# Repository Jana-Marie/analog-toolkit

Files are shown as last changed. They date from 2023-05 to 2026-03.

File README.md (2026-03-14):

# permanently moved to [codeberg/analog-toolkit](https://codeberg.org/analog-toolkit)

# analog-toolkit
A small and simple STM32G431 based dev board, doubling as a simple analog-to-USB acquisition tool.

Next to 6 single ended or 2 differential ADC inputs, there are 3 PGA connected ADC channels, 3 general purpose IO, 2 DAC outputs, 2 Timer outputs, and several protocols such as UART, I2C, USB FS and USB-PD. All ADCs have a standard input resolution of 12 bits, with hardware oversampling up to 16 bits, the DAC has 12 bits resolution. 
Equiped with a DFU bootloader, this board can simply be flashed from USB. All Ports are available through standard 2.54mm pinheader, a scope aligator clip can be attached to the grounding tab. A RGB led allows for direct status indication.

<table>
  <tbody>
    <tr>
      <td>
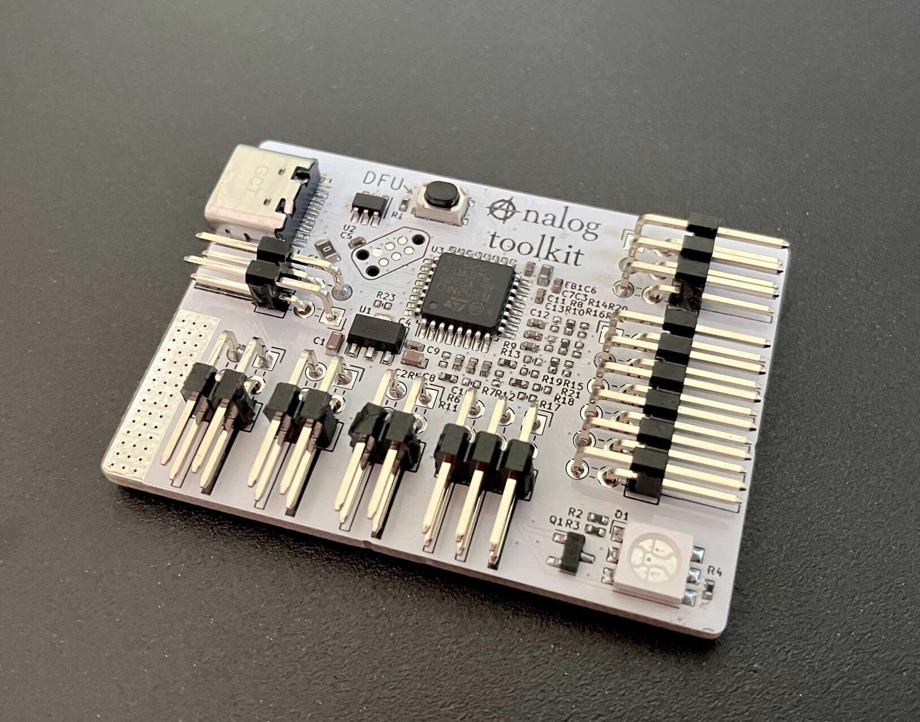
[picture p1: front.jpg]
A white pcb reading “analog toolkit”, where the a is an anarchy a. There is a MCU, USB, pin headers and a led
        
      </td>
      <td>
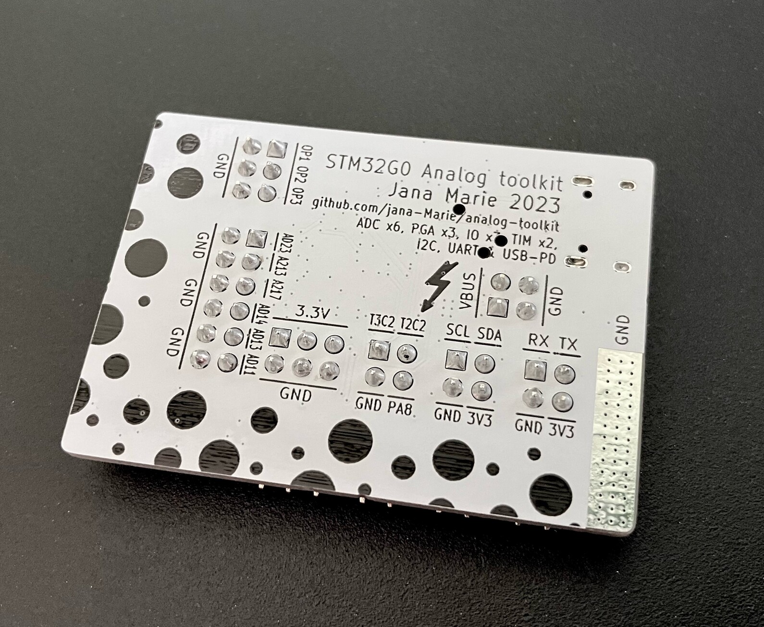
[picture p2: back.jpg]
Back side of the pcb with pin annotations, and some more informations on the hw, as well as silkscreen art
        
      </td>
    </tr>
    <tr>
      <td colspan="2">
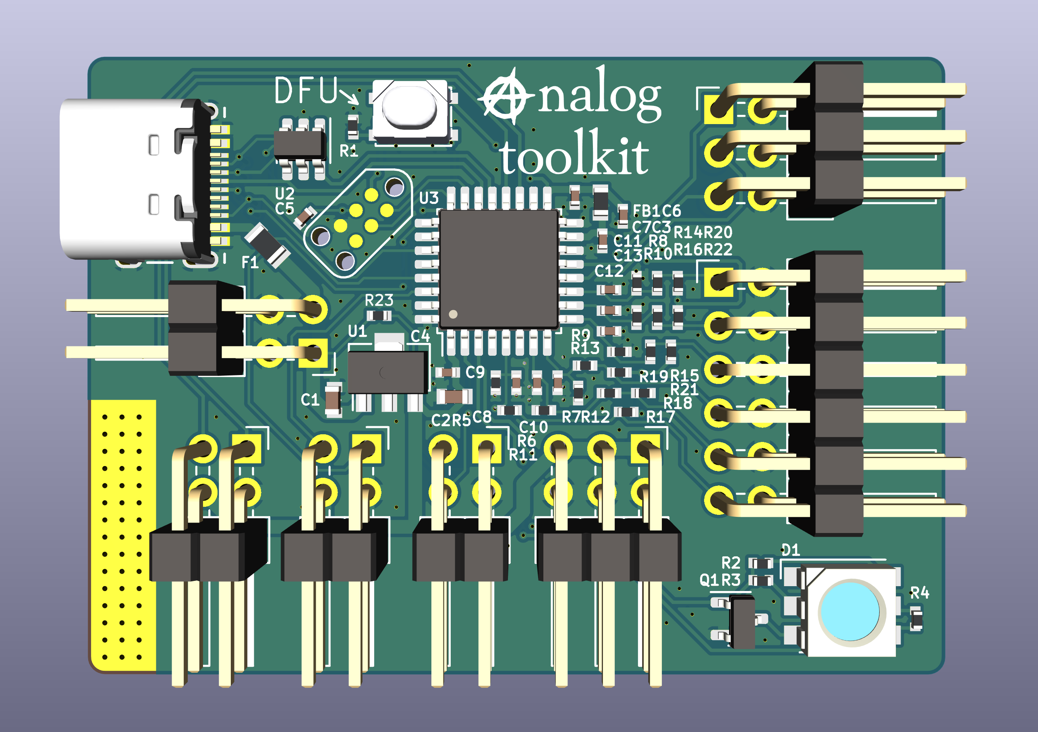
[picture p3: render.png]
render of front side of pcb
        
      </td>
    </tr>
  </tbody>
</table>

## folder structure
```
 /hardware          - PCB files
 /ADC               - ADC sampling firmware, with selectable samplerate and API
 /ADC/software      - python receiving sketch for ADC firmware
 /DAC/              - DAC firmware bit, this one doesn't do much yet
 /pd-dev/           - USB-PD Sink firmware
```

## things I want to do and explore

#### HW

 - [x] replace RGB led with two discrete LEDs
 - [x] cheaper JLC version, keep functionality
 
#### SW/FW

 - [ ] build CLI
   - [ ] build basic CLI firmware
 - [ ] improve ADC fw
   - [ ] add interactive python console (60% done)
   - [ ] PGA current and temperature sensing
   - [ ] Implement byte stuffing
 - [ ] improve DAC fw
   - [ ] make sample rate settable
   - [ ] make sample settable
 - [ ] Implement Sigrok protocol
 - [ ] Implement SCPI
 - [x] USB-PD firmware
 
## license
 
Copyright Jana Marie Hemsing 2026.

This source describes Open Hardware and is licensed under the CERN-OHL-S v2.

You may redistribute and modify this source and make products using it under the terms of the CERN-OHL-S v2 (https://ohwr.org/cern_ohl_s_v2.txt).

This source is distributed WITHOUT ANY EXPRESS OR IMPLIED WARRANTY, INCLUDING OF MERCHANTABILITY, SATISFACTORY QUALITY AND FITNESS FOR A PARTICULAR PURPOSE. Please see the CERN-OHL-S v2 for applicable conditions.

Source location: https://github.com/Jana-Marie/analog-toolkit

As per CERN-OHL-S v2 section 4, should You produce hardware based on this source, You must where practicable maintain the Source Location visible on the external case of the Gizmo or other products you make using this source.

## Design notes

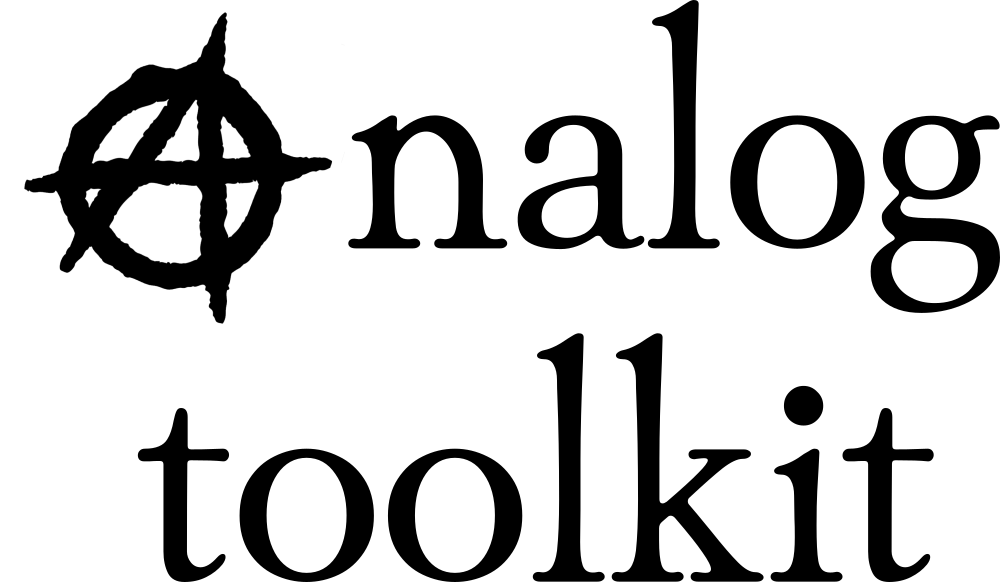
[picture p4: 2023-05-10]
g1298.png

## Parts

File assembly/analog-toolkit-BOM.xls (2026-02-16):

Id | Designator | Footprint | Quantity | Comment | JLCPCB
1 | J1 | USB-C 16Pin | 1 | USB_C | C165948
2 | R4,R2,R3,R1 | R_0402 | 4 | 5k1 | C25905
3 | J2 | PinHeader_2x02_P2.54mm_Horizontal | 1 | IO | C5383087
4 | Q1 | SOT-23 | 1 | AO3400A | C20917
6 | J3 | PinHeader_2x02_P2.54mm_Horizontal | 1 | UART | C5383087
7 | J8 | PinHeader_2x06_P2.54mm_Horizontal | 1 | ADC | C5383091
8 | J6 | PinHeader_2x03_P2.54mm_Horizontal | 1 | 3.3V | C5383088
9 | J4 | PinHeader_2x02_P2.54mm_Horizontal | 1 | I2C | C5383087
10 | C7,C6,C5,C3,C4 | C_0402 | 5 | 100n | C1525
11 | R14,R12,R16,R11,R13,R15 | R_0402 | 6 | 0 | C17168
12 | C12,C11,C8,C9,C10,C13 | C_0402 | 6 | 10n | C15195
13 | U1 | SOT-89-3 | 1 | AP2204R-3.3 | C156303
14 | U2 | SOT-23-6 | 1 | otter_USBLC6-4 | C111212
16 | D1 | LED_RGB_5050-6 | 1 | LED_RGB | C440457
17 | U3 | LQFP-32_7x7mm_P0.8mm | 1 | STM32G431KBT6 | C529357
18 | J5 | PinHeader_2x02_P2.54mm_Horizontal | 1 | VBUS | C5383087
19 | F1 | R_0805 | 1 | 500mA | C17477
20 | FB1 | R_0603 | 1 | FERRET | C1002
21 | C2,C1 | C_0603 | 2 | 4u7 | C19666
22 | SW1 | SW_SPST_PTS810 | 1 | DFU | C115360
23 | J7 | PinHeader_2x03_P2.54mm_Horizontal | 1 | OPAMP | C5383088

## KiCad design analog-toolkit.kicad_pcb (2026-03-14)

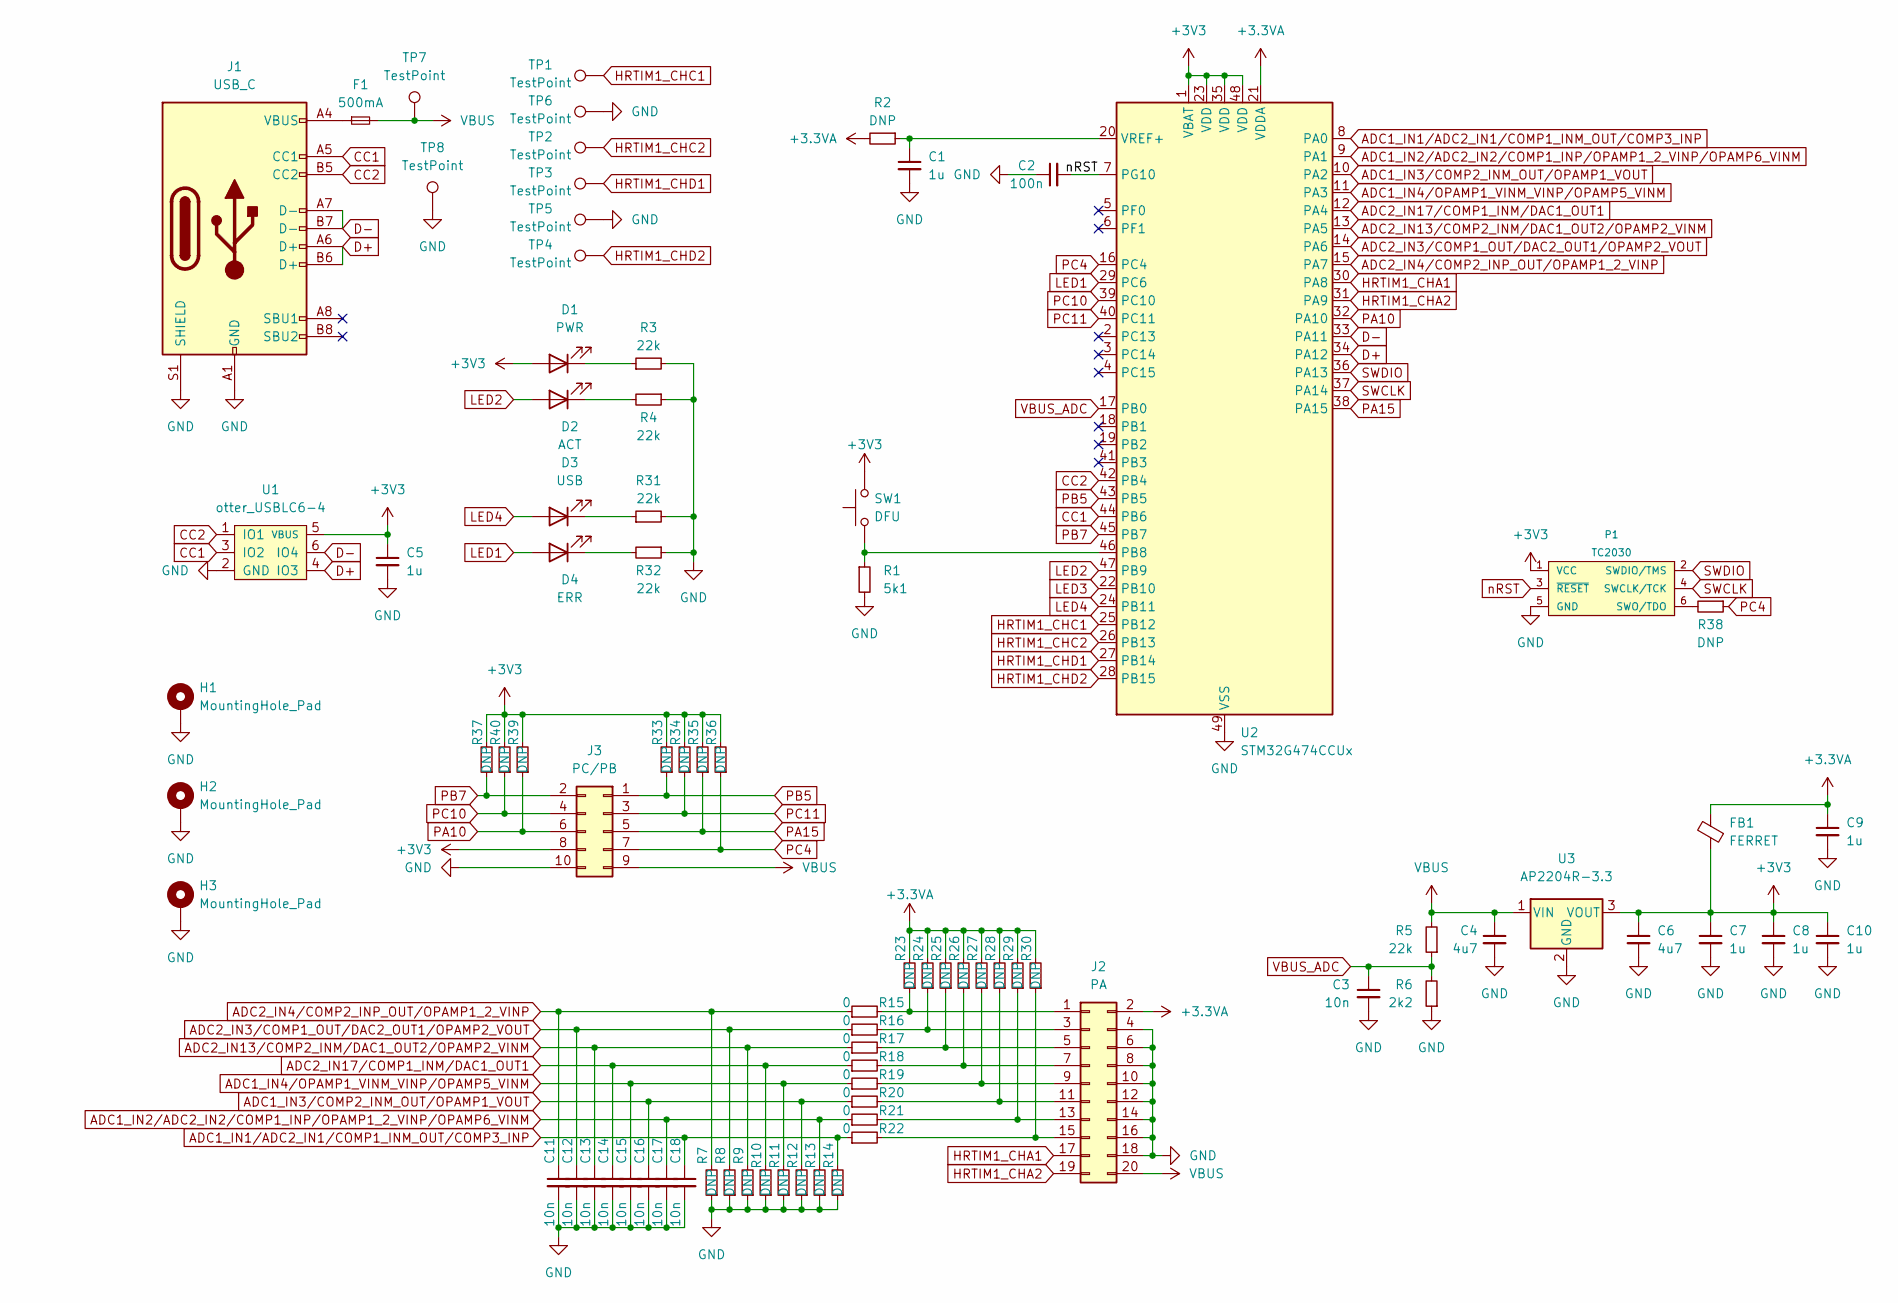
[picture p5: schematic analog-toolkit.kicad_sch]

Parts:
C1, C5, C7, C8, C9, C10: 1u; C_0402; lcsc C52923
C2: 100n; C_0402
C3, C11, C12, C13, C14, C15, C16, C17, C18: 10n; C_0402; lcsc C15195
C4, C6: 4u7; C_0805; lcsc C1779
D1: PWR; LED_0805_2012Metric
D2: ACT; LED_0805_2012Metric
D3: USB; LED_0805_2012Metric
D4: ERR; LED_0805_2012Metric
F1: 500mA; R_0805
FB1: FERRET; R_0603; lcsc C1002
H1, H2, H3: MountingHole_Pad; MountingHole_2.2mm_M2_ISO7380_Pad
J1: USB_C; USB-C 16Pin
J2: PA; IDC-Header_2x10_P2.54mm_Horizontal
J3: PC/PB; IDC-Header_2x05_P2.54mm_Horizontal
P1: TC2030
R1: 5k1; R_0402
R2, R7, R8, R9, R10, R11, R12, R13, R14, R23, R24, R25, R26, R27, R28, R29, R30, R33, R34, R35, R36, R37, R38, R39, R40: DNP; R_0402
R3, R4, R31, R32: 22k; R_0402
R5: 22k; R_0402; lcsc C25768
R6: 2k2; R_0402; lcsc C25890
R15, R16, R17, R18, R19, R20, R21, R22: 0; R_0402; lcsc C17168
SW1: DFU; SW_SPST_PTS810
TP1, TP2, TP3, TP4, TP5, TP6, TP7, TP8: TestPoint; TestPoint_Pad_1.0x1.0mm
U1: otter_USBLC6-4; SOT-23-6
U2: STM32G474CCUx; QFN-48-1EP_7x7mm_P0.5mm_EP5.6x5.6mm
U3: AP2204R-3.3; SOT-89-3

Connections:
+3.3VA: C9.1, FB1.2, J2.2, R2.2, R23.2, R24.2, R25.2, R26.2, R27.2, R28.2, R29.2, R30.2, U2.21 (VDDA)
+3V3: C5.1, C6.1, C7.1, C8.1, C10.1, D1.2 (A), FB1.1, J3.8, P1.1 (VCC), R33.2, R34.2, R35.2, R36.2, R37.2, R39.2, R40.2, SW1.2, U1.5 (VBUS), U2.1 (VBAT), U2.23 (VDD), U2.35 (VDD), U2.48 (VDD), U3.3 (VOUT)
ADC1_IN1/ADC2_IN1/COMP1_INM_OUT/COMP3_INP: C18.1, R14.2, R22.1, U2.8 (PA0)
ADC1_IN2/ADC2_IN2/COMP1_INP/OPAMP1_2_VINP/OPAMP6_VINM: C17.1, R13.2, R21.1, U2.9 (PA1)
ADC1_IN3/COMP2_INM_OUT/OPAMP1_VOUT: C16.1, R12.2, R20.1, U2.10 (PA2)
ADC1_IN4/OPAMP1_VINM_VINP/OPAMP5_VINM: C15.1, R11.2, R19.1, U2.11 (PA3)
ADC2_IN3/COMP1_OUT/DAC2_OUT1/OPAMP2_VOUT: C12.1, R8.2, R16.1, U2.14 (PA6)
ADC2_IN4/COMP2_INP_OUT/OPAMP1_2_VINP: C11.1, R7.2, R15.1, U2.15 (PA7)
ADC2_IN13/COMP2_INM/DAC1_OUT2/OPAMP2_VINM: C13.1, R9.2, R17.1, U2.13 (PA5)
ADC2_IN17/COMP1_INM/DAC1_OUT1: C14.1, R10.2, R18.1, U2.12 (PA4)
CC1: J1.A5 (CC1), U1.3 (IO2), U2.44 (PB6)
CC2: J1.B5 (CC2), U1.1 (IO1), U2.42 (PB4)
D+: J1.A6 (D+), J1.B6 (D+), U1.4 (IO3), U2.34 (PA12)
D-: J1.A7 (D-), J1.B7 (D-), U1.6 (IO4), U2.33 (PA11)
GND: C1.2, C2.1, C3.2, C4.2, C5.2, C6.2, C7.2, C8.2, C9.2, C10.2, C11.2, C12.2, C13.2, C14.2, C15.2, C16.2, C17.2, C18.2, H1.1, H2.1, H3.1, J1.A1 (GND), J1.A12 (GND), J1.B1 (GND), J1.B12 (GND), J1.S1 (SHIELD), J2.4, J2.6, J2.8, J2.10, J2.12, J2.14, J2.16, J2.18, J3.10, P1.5 (GND), R1.2, R3.2, R4.1, R6.1, R7.1, R8.1, R9.1, R10.1, R11.1, R12.1, R13.1, R14.1, R31.2, R32.1, TP5.1, TP6.1, TP8.1, U1.2 (GND), U2.49 (VSS), U3.2 (GND)
HRTIM1_CHA1: J2.17, U2.30 (PA8)
HRTIM1_CHA2: J2.19, U2.31 (PA9)
HRTIM1_CHC1: TP1.1, U2.25 (PB12)
HRTIM1_CHC2: TP2.1, U2.26 (PB13)
HRTIM1_CHD1: TP3.1, U2.27 (PB14)
HRTIM1_CHD2: TP4.1, U2.28 (PB15)
LED1: D4.2 (A), U2.29 (PC6)
LED2: D2.2 (A), U2.47 (PB9)
LED3: U2.22 (PB10)
LED4: D3.2 (A), U2.24 (PB11)
unnamed: D1.1 (K), R3.1
unnamed: D2.1 (K), R4.2
unnamed: D3.1 (K), R31.1
unnamed: D4.1 (K), R32.2
unnamed: F1.1, J1.A4 (VBUS), J1.A9 (VBUS), J1.B4 (VBUS), J1.B9 (VBUS)
unnamed: J2.1, R15.2, R23.1
unnamed: J2.3, R16.2, R24.1
unnamed: J2.5, R17.2, R25.1
unnamed: J2.7, R18.2, R26.1
unnamed: J2.9, R19.2, R27.1
unnamed: J2.11, R20.2, R28.1
unnamed: J2.13, R21.2, R29.1
unnamed: J2.15, R22.2, R30.1
unnamed: P1.6 (SWO/TDO), R38.2
unnamed: R1.1, SW1.1, U2.46 (PB8)
unnamed: C1.1, R2.1, U2.20 (VREF+)
PA10: J3.6, R39.1, U2.32 (PA10)
PA15: J3.5, R35.1, U2.38 (PA15)
PB5: J3.1, R33.1, U2.43 (PB5)
PB7: J3.2, R37.1, U2.45 (PB7)
PC4: J3.7, R36.1, R38.1, U2.16 (PC4)
PC10: J3.4, R40.1, U2.39 (PC10)
PC11: J3.3, R34.1, U2.40 (PC11)
SWCLK: P1.4 (SWCLK/TCK), U2.37 (PA14)
SWDIO: P1.2 (SWDIO/TMS), U2.36 (PA13)
VBUS: C4.1, F1.2, J2.20, J3.9, R5.2, TP7.1, U3.1 (VIN)
VBUS_ADC: C3.1, R5.1, R6.2, U2.17 (PB0)
nRST: C2.2, P1.3 (~RESET), U2.7 (PG10)

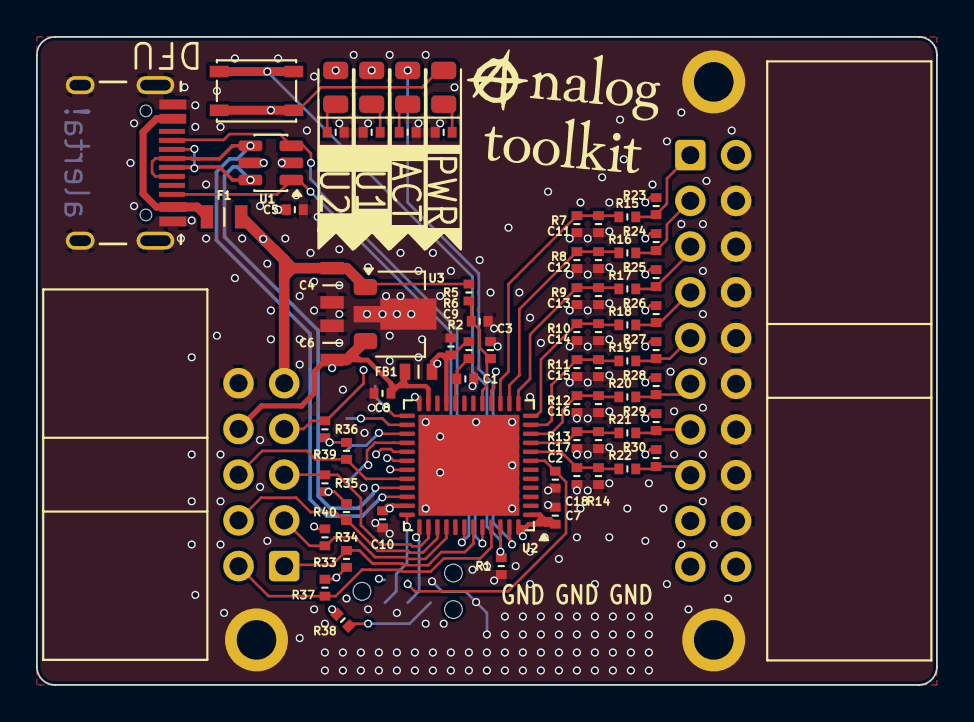
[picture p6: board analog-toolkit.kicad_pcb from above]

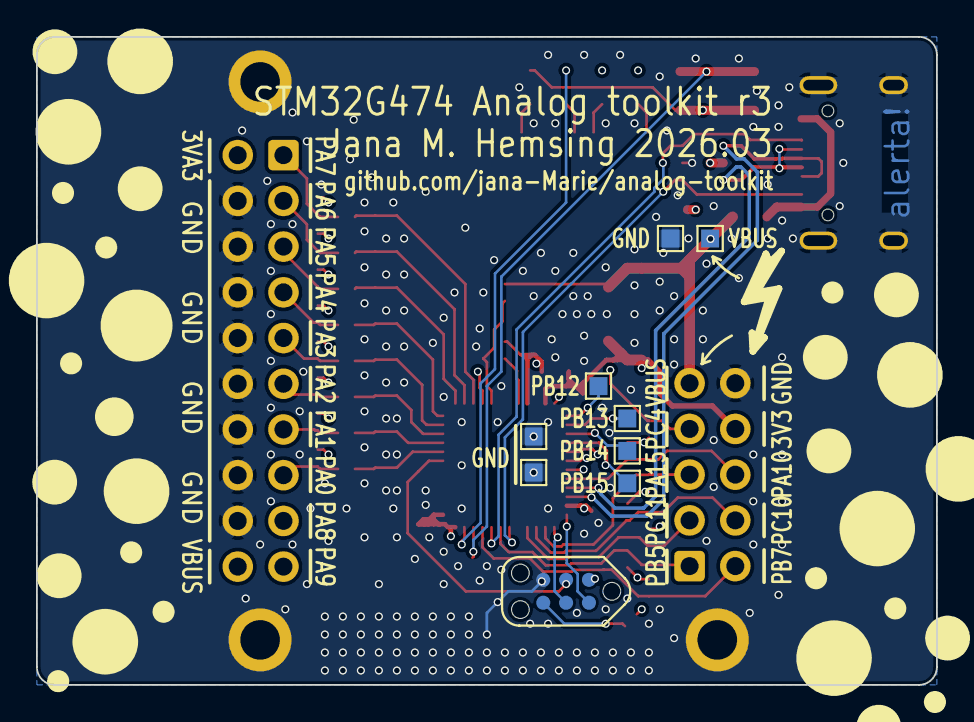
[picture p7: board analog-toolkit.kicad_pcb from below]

Board: 4 copper layers, 50.0 x 36.0 mm, 83 parts (9 on the bottom side), 52 nets.

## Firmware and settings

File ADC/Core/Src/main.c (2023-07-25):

#include "main.h"
#include "usbpd.h"
#include "usb_device.h"
#include "usbd_cdc_if.h"
//#include <math.h>

#define CLAMP(x, low, high) (((x) > (high)) ? (high) : (((x) < (low)) ? (low) : (x)))
#define ABS(x) ((x) < 0 ? -(x) : (x))

ADC_HandleTypeDef hadc1;
ADC_HandleTypeDef hadc2;
DMA_HandleTypeDef hdma_adc1;
DMA_HandleTypeDef hdma_adc2;

CORDIC_HandleTypeDef hcordic;

FMAC_HandleTypeDef hfmac;

I2C_HandleTypeDef hi2c1;

OPAMP_HandleTypeDef hopamp1;
OPAMP_HandleTypeDef hopamp2;
OPAMP_HandleTypeDef hopamp3;

RNG_HandleTypeDef hrng;

TIM_HandleTypeDef htim2;
TIM_HandleTypeDef htim3;
TIM_HandleTypeDef htim4;
TIM_HandleTypeDef htim6;
TIM_HandleTypeDef htim8;

UART_HandleTypeDef huart1;

enum led_states {LED_OFF = 0, LED_READY, LED_RUNNING, LED_DONE, LED_ERROR};
enum fsm_states {IDLE = 0, INIT, RUNNING, DONE, ERR};

// FLAGS
uint8_t evaluate_FSM = 0;

struct fsm_t {
  uint8_t led; // led mode
  uint8_t mode; // FSM mode
} fsm;

uint16_t adc[9]; // ADC buf

struct settings_t {
  uint32_t samplingFreq; // sampling frequency
  uint16_t psc; // sampling frequency
  uint16_t arr; // sampling frequency
  uint16_t OverSampling; // oversampling ration; 0, x2, x4, x8, x16
  uint16_t PGAgain[3]; // PGA gain
  uint8_t configChanged; // flag for config has changed 2^0 frequency has changed; 2^1 psc, arr has changed; 2^2 PGA has changed
  uint8_t telegramSize;
} settings;

uint8_t usbDataReady; // flag for data ready
uint16_t usbDataLength; // length of USB data
uint8_t usbBuf[32]; // data buffer

uint8_t adcDMAready = 0;
struct telegram_t {
  uint16_t data[257][9];
  uint16_t idx; // current index
  uint16_t lastidx; // last index
  uint16_t sendcnt; // send counter
} t;

struct usb_t {
  uint8_t state; // state to determine wether the USB send flag should be set
  uint8_t send; // flag for USB send
  uint8_t res; // usb send result flag
} usb;

void SystemClock_Config(void);
static void MX_GPIO_Init(void);
static void MX_DMA_Init(void);
static void MX_UCPD1_Init(void);
static void MX_ADC1_Init(void);
static void MX_ADC2_Init(void);
static void MX_OPAMP1_Init(void);
static void MX_OPAMP2_Init(void);
static void MX_OPAMP3_Init(void);
static void MX_I2C1_Init(void);
static void MX_USART1_UART_Init(void);
static void MX_CORDIC_Init(void);
static void MX_FMAC_Init(void);
static void MX_RNG_Init(void);
static void MX_TIM2_Init(void);
static void MX_TIM3_Init(void);
static void MX_TIM4_Init(void);
static void MX_TIM8_Init(void);
static void MX_TIM6_Init(void);
void led_task(void);
void get_timer_value(struct settings_t *set);
void settings_task(struct settings_t *set);
void adc_task(void);
void fsm_task(void);
void send_usb(uint8_t len);
void usb_parser(void);

int main(void)
{
  HAL_Init();
  SystemClock_Config();
  MX_GPIO_Init();
  MX_DMA_Init();
  MX_UCPD1_Init();
  MX_USB_Device_Init();
  MX_ADC1_Init();
  MX_ADC2_Init();
  MX_OPAMP1_Init();
  MX_OPAMP2_Init();
  MX_OPAMP3_Init();
  MX_I2C1_Init();
  MX_USART1_UART_Init();
  MX_CORDIC_Init();
  MX_FMAC_Init();
  MX_RNG_Init();
  MX_TIM2_Init();
  MX_TIM3_Init();
  MX_TIM4_Init();
  MX_TIM8_Init();
  MX_TIM6_Init();

  // LED
  HAL_TIM_Base_Start_IT(&htim6);
  // ADC
  HAL_ADC_Start_DMA(&hadc1, (uint32_t *) &adc[0], 4);
  HAL_ADC_Start_DMA(&hadc2, (uint32_t *) &adc[4], 5);
  HAL_TIM_Base_Start_IT(&htim4);

  settings.samplingFreq = 100;
  settings.configChanged = 1;
  settings.telegramSize = 127;

  //MX_USBPD_Init();
  while (1)
  {
    //USBPD_DPM_Run();
    settings_task(&settings);

    //if(adc_ready) adc_task();
    if(evaluate_FSM) fsm_task();
    //if(evaluate_LED) led_task();
    if(usbDataReady) usb_parser();

  }
}

uint32_t number;
void usb_parser(){
  if(usbDataLength >= 4){
    // extract channel number, char - 48 (or ascii '0') = sent integer
    //uint8_t channel = usb_buf[3] - '0';
    number = atoi((char *)usbBuf + 3);

    if(strncmp("SPS", (char *) usbBuf, 3) == 0){
      if(number > 0 && number < 100000){
        settings.samplingFreq = number;
      }
    } else if(strncmp("SET", (char *) usbBuf, 3) == 0) {
      settings.configChanged = 1;
    }
    // else if(strncmp("RST", (char *) usb_buf, 3) == 0){
    //  t[channel].rst = 1;
    //}

    /*else if(strncmp("STR", (char *) usb_buf, 3) == 0){
      telegram[channel].usb.state = 1;
    } else if(strncmp("STP", (char *) usb_buf, 3) == 0){
      telegram[channel].usb.state = 0;
    } else if(strncmp("STP", (char *) usb_buf, 3) == 0){
      telegram[channel].usb.state = 0;
    } else if(strncmp("STP", (char *) usb_buf, 3) == 0){
      telegram[channel].usb.state = 0;
    } else if(strncmp("HST", (char *) usb_buf, 3) == 0){
      for(uint8_t i = 0; i <= HISTORY-1; i++){
        send_telegram(telegram[channel].serialNumber, &telegram[channel].hist[i]);
      }
    } else if(strncmp("TSK", (char *) usb_buf, 3) == 0){
      memcpy((void *)&t[channel], (void *)&usb_buf[4], 28);
    } else {
      CDC_Transmit_FS((uint8_t *) "Could not parse command\r\n", 25);
    }
    */
  }
  usbDataReady = 0;
}

uint8_t idx = 0;
uint16_t curridx;
void send_usb(uint8_t len){
  if(t.idx == 0){
    idx = 255;
  } else {
    idx = t.idx;
  }

  HAL_GPIO_WritePin(GPIOF, GPIO_PIN_1, 1);

  char package[len][56];
  for(uint16_t i = 0; i < len; i++){
    memset(package[i], '\0' , 56);
    curridx = (i + t.lastidx) % 256;
    sprintf(package[i], "%lu,%u,%u,%u,%u,%u,%u,%u,%u,%u\r\n", HAL_GetTick(),
                                                              t.data[curridx][0],
                                                              t.data[curridx][1],
                                                              t.data[curridx][2],
                                                              t.data[curridx][3],
                                                              t.data[curridx][4],
                                                              t.data[curridx][5],
                                                              t.data[curridx][6],
                                                              t.data[curridx][7],
                                                              t.data[curridx][8]);
  }

  usb.res = CDC_Transmit_FS((uint8_t *) package, 56*len);

  t.lastidx = idx;

  HAL_GPIO_WritePin(GPIOF, GPIO_PIN_1, 0);
}

uint8_t idxdif = 0;
void adc_task(){
  if(adcDMAready == 3){
    adcDMAready = 0;
    memcpy(&t.data[t.idx][0], &adc[0], 18);

    t.idx = (t.idx <= 255) ? (t.idx + 1) : 0;

    t.sendcnt++;

    if(t.sendcnt > settings.telegramSize){
      send_usb(t.sendcnt);
      t.sendcnt = 0;
    }
  }
}

// finite state machine
void fsm_task(){
    switch (fsm.mode){
      case IDLE:
      default:
        // Idle means:
        //   - Adapt to settings
        //   - Start on USB command

        if(0){
          fsm.mode = ERROR;
        } else if(0){
          fsm.mode = RUNNING;
        }
        break;
      case INIT:
        // ADC
        HAL_ADC_Start_DMA(&hadc1, (uint32_t *) &adc[0], 4);
        HAL_ADC_Start_DMA(&hadc2, (uint32_t *) &adc[4], 5);
        HAL_TIM_Base_Start_IT(&htim4);

        t.idx = 0;

        if(0){
          fsm.mode = ERROR;
        } else {
          fsm.mode = RUNNING;
        }
        break;
      case RUNNING:
        // Running means:
        //   - Collect ADC Samples
        //   - Send to USB
        //   - Adapt to change in settings
        
        usb.send = 1;
        

        if(0){
          fsm.mode = ERROR;
        } else if(0){
          fsm.mode = DONE;
        }
        break;
      case DONE:
        // Done means:
        //   - Finished with the task
        //   - Cleanup and return to IDLE

        if(0){
          fsm.mode = IDLE;
        }
        break;
      case ERR:
        // Error means:
        //   - Something went wrong, not sure what this means yet

        // if error reset
        if(0){
          fsm.mode = IDLE;
        }
        break;
    }
}

void led_task(){
  /*
  switch (fsm.led){
  case LED_OFF:
  default:
    HAL_GPIO_WritePin(GPIOF, GPIO_PIN_0, 0);
    HAL_GPIO_WritePin(GPIOF, GPIO_PIN_1, 0);
    break;
  case LED_READY:
    HAL_GPIO_WritePin(GPIOF, GPIO_PIN_0, 0);
    HAL_GPIO_WritePin(GPIOF, GPIO_PIN_1, 1);
    break;
  case LED_RUNNING:
    HAL_GPIO_WritePin(GPIOF, GPIO_PIN_0, 1);
    HAL_GPIO_TogglePin(GPIOF, GPIO_PIN_1);
    break;
  case LED_DONE:
    if(HAL_GPIO_ReadPin(GPIOF, GPIO_PIN_0) == HAL_GPIO_ReadPin(GPIOF, GPIO_PIN_1))HAL_GPIO_TogglePin(GPIOF, GPIO_PIN_0);
    HAL_GPIO_TogglePin(GPIOF, GPIO_PIN_0);
    HAL_GPIO_TogglePin(GPIOF, GPIO_PIN_1);
    break;
  case LED_ERROR:
    HAL_GPIO_WritePin(GPIOF, GPIO_PIN_0, 1);
    HAL_GPIO_WritePin(GPIOF, GPIO_PIN_1, 0);
    break;
  }
  */
}

// settings
void settings_task(struct settings_t *set){
  if(set->configChanged == 1){
    get_timer_value(set);
    set->configChanged &= ~(1);
  }
  if(set->configChanged == 2){
    set->configChanged &= ~(1 << 1);
    __HAL_TIM_SET_PRESCALER(&htim4, set->psc);
    TIM4->ARR = set->arr;

    settings.telegramSize = CLAMP(settings.samplingFreq / 10, 1, 196);
  }

}

uint32_t fake_power(uint32_t m, uint32_t n){
  if(n <= 0) return 0;
  uint32_t result = 10;
  for(uint8_t i = 0; i < n-1; i++){
    result *= 10;
  }
  return result;
}

// calculate timer values
void get_timer_value(struct settings_t *set){
    uint32_t num = 168000000/set->samplingFreq;
    uint8_t n = 0;
    while (num > 65534) {
      n += 1;
      num = num/10;
    };
    set->psc = fake_power(10, n);
    if(set->psc > 0) set->psc -= 1;
    set->arr = num - 1;
    set->configChanged += 2;
}

void SystemClock_Config(void)
{
  RCC_OscInitTypeDef RCC_OscInitStruct = {0};
  RCC_ClkInitTypeDef RCC_ClkInitStruct = {0};

  HAL_PWREx_ControlVoltageScaling(PWR_REGULATOR_VOLTAGE_SCALE1_BOOST);

  RCC_OscInitStruct.OscillatorType = RCC_OSCILLATORTYPE_HSI|RCC_OSCILLATORTYPE_HSI48;
  RCC_OscInitStruct.HSIState = RCC_HSI_ON;
  RCC_OscInitStruct.HSICalibrationValue = RCC_HSICALIBRATION_DEFAULT;
  RCC_OscInitStruct.HSI48State = RCC_HSI48_ON;
  RCC_OscInitStruct.PLL.PLLState = RCC_PLL_ON;
  RCC_OscInitStruct.PLL.PLLSource = RCC_PLLSOURCE_HSI;
  RCC_OscInitStruct.PLL.PLLM = RCC_PLLM_DIV1;
  RCC_OscInitStruct.PLL.PLLN = 21;
  RCC_OscInitStruct.PLL.PLLP = RCC_PLLP_DIV2;
  RCC_OscInitStruct.PLL.PLLQ = RCC_PLLQ_DIV4;
  RCC_OscInitStruct.PLL.PLLR = RCC_PLLR_DIV2;
  HAL_RCC_OscConfig(&RCC_OscInitStruct);
  
  RCC_ClkInitStruct.ClockType = RCC_CLOCKTYPE_HCLK|RCC_CLOCKTYPE_SYSCLK
                              |RCC_CLOCKTYPE_PCLK1|RCC_CLOCKTYPE_PCLK2;
  RCC_ClkInitStruct.SYSCLKSource = RCC_SYSCLKSOURCE_PLLCLK;
  RCC_ClkInitStruct.AHBCLKDivider = RCC_SYSCLK_DIV1;
  RCC_ClkInitStruct.APB1CLKDivider = RCC_HCLK_DIV1;
  RCC_ClkInitStruct.APB2CLKDivider = RCC_HCLK_DIV1;

  HAL_RCC_ClockConfig(&RCC_ClkInitStruct, FLASH_LATENCY_4);
}

static void MX_ADC1_Init(void)
{
  ADC_MultiModeTypeDef multimode = {0};
  ADC_ChannelConfTypeDef sConfig = {0};

  hadc1.Instance = ADC1;
  hadc1.Init.ClockPrescaler = ADC_CLOCK_SYNC_PCLK_DIV4;
  hadc1.Init.Resolution = ADC_RESOLUTION_12B;
  hadc1.Init.DataAlign = ADC_DATAALIGN_RIGHT;
  hadc1.Init.GainCompensation = 0;
  hadc1.Init.ScanConvMode = ADC_SCAN_ENABLE;
  hadc1.Init.EOCSelection = ADC_EOC_SEQ_CONV;
  hadc1.Init.LowPowerAutoWait = DISABLE;
  hadc1.Init.ContinuousConvMode = DISABLE;
  hadc1.Init.NbrOfConversion = 4;
  hadc1.Init.DiscontinuousConvMode = DISABLE;
  hadc1.Init.ExternalTrigConv = ADC_EXTERNALTRIG_T4_TRGO;
  hadc1.Init.ExternalTrigConvEdge = ADC_EXTERNALTRIGCONVEDGE_RISING;
  hadc1.Init.DMAContinuousRequests = ENABLE;
  hadc1.Init.Overrun = ADC_OVR_DATA_PRESERVED;
  hadc1.Init.OversamplingMode = DISABLE;
  hadc1.Init.Oversampling.Ratio = ADC_OVERSAMPLING_RATIO_2;
  hadc1.Init.Oversampling.RightBitShift = ADC_RIGHTBITSHIFT_NONE;
  hadc1.Init.Oversampling.TriggeredMode = ADC_TRIGGEREDMODE_SINGLE_TRIGGER;
  hadc1.Init.Oversampling.OversamplingStopReset = ADC_REGOVERSAMPLING_CONTINUED_MODE;
  HAL_ADC_Init(&hadc1);

  multimode.Mode = ADC_MODE_INDEPENDENT;
  multimode.DMAAccessMode = ADC_DMAACCESSMODE_DISABLED;
  multimode.TwoSamplingDelay = ADC_TWOSAMPLINGDELAY_1CYCLE;
  HAL_ADCEx_MultiModeConfigChannel(&hadc1, &multimode);

  sConfig.Channel = ADC_CHANNEL_1;
  sConfig.Rank = ADC_REGULAR_RANK_1;
  sConfig.SamplingTime = ADC_SAMPLETIME_2CYCLES_5;
  sConfig.SingleDiff = ADC_SINGLE_ENDED;
  sConfig.OffsetNumber = ADC_OFFSET_NONE;
  sConfig.Offset = 0;
  HAL_ADC_ConfigChannel(&hadc1, &sConfig);

  sConfig.Channel = ADC_CHANNEL_2;
  sConfig.Rank = ADC_REGULAR_RANK_2;
  HAL_ADC_ConfigChannel(&hadc1, &sConfig);

  sConfig.Channel = ADC_CHANNEL_3;
  sConfig.Rank = ADC_REGULAR_RANK_3;
  HAL_ADC_ConfigChannel(&hadc1, &sConfig);

  sConfig.Channel = ADC_CHANNEL_VOPAMP1;
  sConfig.Rank = ADC_REGULAR_RANK_4;
  HAL_ADC_ConfigChannel(&hadc1, &sConfig);
}

static void MX_ADC2_Init(void)
{
  ADC_MultiModeTypeDef multimode = {0};
  ADC_ChannelConfTypeDef sConfig = {0};

  hadc2.Instance = ADC2;
  hadc2.Init.ClockPrescaler = ADC_CLOCK_SYNC_PCLK_DIV4;
  hadc2.Init.Resolution = ADC_RESOLUTION_12B;
  hadc2.Init.DataAlign = ADC_DATAALIGN_RIGHT;
  hadc2.Init.GainCompensation = 0;
  hadc2.Init.ScanConvMode = ADC_SCAN_ENABLE;
  hadc2.Init.EOCSelection = ADC_EOC_SEQ_CONV;
  hadc2.Init.LowPowerAutoWait = DISABLE;
  hadc2.Init.ContinuousConvMode = DISABLE;
  hadc2.Init.NbrOfConversion = 5;
  hadc2.Init.DiscontinuousConvMode = DISABLE;
  hadc2.Init.ExternalTrigConv = ADC_EXTERNALTRIG_T4_TRGO;
  hadc2.Init.ExternalTrigConvEdge = ADC_EXTERNALTRIGCONVEDGE_RISING;
  hadc2.Init.DMAContinuousRequests = ENABLE;
  hadc2.Init.Overrun = ADC_OVR_DATA_PRESERVED;
  hadc2.Init.OversamplingMode = DISABLE;
  hadc2.Init.Oversampling.Ratio = ADC_OVERSAMPLING_RATIO_2;
  hadc2.Init.Oversampling.RightBitShift = ADC_RIGHTBITSHIFT_NONE;
  hadc2.Init.Oversampling.TriggeredMode = ADC_TRIGGEREDMODE_SINGLE_TRIGGER;
  hadc2.Init.Oversampling.OversamplingStopReset = ADC_REGOVERSAMPLING_CONTINUED_MODE;
  HAL_ADC_Init(&hadc2);

  multimode.Mode = ADC_MODE_INDEPENDENT;
  multimode.DMAAccessMode = ADC_DMAACCESSMODE_DISABLED;
  multimode.TwoSamplingDelay = ADC_TWOSAMPLINGDELAY_1CYCLE;
  HAL_ADCEx_MultiModeConfigChannel(&hadc2, &multimode);

  sConfig.Channel = ADC_CHANNEL_3;
  sConfig.Rank = ADC_REGULAR_RANK_1;
  sConfig.SamplingTime = ADC_SAMPLETIME_2CYCLES_5;
  sConfig.SingleDiff = ADC_SINGLE_ENDED;
  sConfig.OffsetNumber = ADC_OFFSET_NONE;
  sConfig.Offset = 0;
  HAL_ADC_ConfigChannel(&hadc2, &sConfig);

  sConfig.Channel = ADC_CHANNEL_13;
  sConfig.Rank = ADC_REGULAR_RANK_2;
  HAL_ADC_ConfigChannel(&hadc2, &sConfig);

  sConfig.Channel = ADC_CHANNEL_17;
  sConfig.Rank = ADC_REGULAR_RANK_3;
  HAL_ADC_ConfigChannel(&hadc2, &sConfig);

  sConfig.Channel = ADC_CHANNEL_VOPAMP2;
  sConfig.Rank = ADC_REGULAR_RANK_4;
  HAL_ADC_ConfigChannel(&hadc2, &sConfig);

  sConfig.Channel = ADC_CHANNEL_VOPAMP3_ADC2;
  sConfig.Rank = ADC_REGULAR_RANK_5;
  HAL_ADC_ConfigChannel(&hadc2, &sConfig);
}

static void MX_CORDIC_Init(void)
{
  hcordic.Instance = CORDIC;
  HAL_CORDIC_Init(&hcordic);
}

static void MX_FMAC_Init(void)
{
  hfmac.Instance = FMAC;
  HAL_FMAC_Init(&hfmac);
}

static void MX_I2C1_Init(void)
{
  hi2c1.Instance = I2C1;
  hi2c1.Init.Timing = 0x20501E65;
  hi2c1.Init.OwnAddress1 = 0;
  hi2c1.Init.AddressingMode = I2C_ADDRESSINGMODE_7BIT;
  hi2c1.Init.DualAddressMode = I2C_DUALADDRESS_DISABLE;
  hi2c1.Init.OwnAddress2 = 0;
  hi2c1.Init.OwnAddress2Masks = I2C_OA2_NOMASK;
  hi2c1.Init.GeneralCallMode = I2C_GENERALCALL_DISABLE;
  hi2c1.Init.NoStretchMode = I2C_NOSTRETCH_DISABLE;
  HAL_I2C_Init(&hi2c1);
  HAL_I2CEx_ConfigAnalogFilter(&hi2c1, I2C_ANALOGFILTER_ENABLE);
  HAL_I2CEx_ConfigDigitalFilter(&hi2c1, 0);
}

static void MX_OPAMP1_Init(void)
{
  hopamp1.Instance = OPAMP1;
  hopamp1.Init.PowerMode = OPAMP_POWERMODE_HIGHSPEED;
  hopamp1.Init.Mode = OPAMP_PGA_MODE;
  hopamp1.Init.NonInvertingInput = OPAMP_NONINVERTINGINPUT_IO0;
  hopamp1.Init.InternalOutput = ENABLE;
  hopamp1.Init.TimerControlledMuxmode = OPAMP_TIMERCONTROLLEDMUXMODE_DISABLE;
  hopamp1.Init.PgaConnect = OPAMP_PGA_CONNECT_INVERTINGINPUT_NO;
  hopamp1.Init.PgaGain = OPAMP_PGA_GAIN_2_OR_MINUS_1;
  hopamp1.Init.UserTrimming = OPAMP_TRIMMING_FACTORY;
  HAL_OPAMP_Init(&hopamp1);
}

static void MX_OPAMP2_Init(void)
{
  hopamp2.Instance = OPAMP2;
  hopamp2.Init.PowerMode = OPAMP_POWERMODE_HIGHSPEED;
  hopamp2.Init.Mode = OPAMP_PGA_MODE;
  hopamp2.Init.NonInvertingInput = OPAMP_NONINVERTINGINPUT_IO0;
  hopamp2.Init.InternalOutput = ENABLE;
  hopamp2.Init.TimerControlledMuxmode = OPAMP_TIMERCONTROLLEDMUXMODE_DISABLE;
  hopamp2.Init.PgaConnect = OPAMP_PGA_CONNECT_INVERTINGINPUT_NO;
  hopamp2.Init.PgaGain = OPAMP_PGA_GAIN_2_OR_MINUS_1;
  hopamp2.Init.UserTrimming = OPAMP_TRIMMING_FACTORY;
  HAL_OPAMP_Init(&hopamp2);
}

static void MX_OPAMP3_Init(void)
{
  hopamp3.Instance = OPAMP3;
  hopamp3.Init.PowerMode = OPAMP_POWERMODE_HIGHSPEED;
  hopamp3.Init.Mode = OPAMP_FOLLOWER_MODE;
  hopamp3.Init.NonInvertingInput = OPAMP_NONINVERTINGINPUT_IO0;
  hopamp3.Init.InternalOutput = ENABLE;
  hopamp3.Init.TimerControlledMuxmode = OPAMP_TIMERCONTROLLEDMUXMODE_DISABLE;
  hopamp3.Init.UserTrimming = OPAMP_TRIMMING_FACTORY;
  HAL_OPAMP_Init(&hopamp3);
}

static void MX_RNG_Init(void)
{
  hrng.Instance = RNG;
  hrng.Init.ClockErrorDetection = RNG_CED_ENABLE;
  HAL_RNG_Init(&hrng);
}

static void MX_TIM2_Init(void)
{
  TIM_ClockConfigTypeDef sClockSourceConfig = {0};
  TIM_MasterConfigTypeDef sMasterConfig = {0};
  TIM_OC_InitTypeDef sConfigOC = {0};

  htim2.Instance = TIM2;
  htim2.Init.Prescaler = 99;
  htim2.Init.CounterMode = TIM_COUNTERMODE_UP;
  htim2.Init.Period = 4999;
  htim2.Init.ClockDivision = TIM_CLOCKDIVISION_DIV1;
  htim2.Init.AutoReloadPreload = TIM_AUTORELOAD_PRELOAD_DISABLE;
  HAL_TIM_Base_Init(&htim2);

  sClockSourceConfig.ClockSource = TIM_CLOCKSOURCE_INTERNAL;
  HAL_TIM_ConfigClockSource(&htim2, &sClockSourceConfig);

  HAL_TIM_PWM_Init(&htim2);

  sMasterConfig.MasterOutputTrigger = TIM_TRGO_RESET;
  sMasterConfig.MasterSlaveMode = TIM_MASTERSLAVEMODE_DISABLE;
  HAL_TIMEx_MasterConfigSynchronization(&htim2, &sMasterConfig);

  sConfigOC.OCMode = TIM_OCMODE_PWM1;
  sConfigOC.Pulse = 0;
  sConfigOC.OCPolarity = TIM_OCPOLARITY_HIGH;
  sConfigOC.OCFastMode = TIM_OCFAST_DISABLE;
  HAL_TIM_PWM_ConfigChannel(&htim2, &sConfigOC, TIM_CHANNEL_2);

  HAL_TIM_MspPostInit(&htim2);
}

static void MX_TIM3_Init(void)
{
  TIM_ClockConfigTypeDef sClockSourceConfig = {0};
  TIM_MasterConfigTypeDef sMasterConfig = {0};
  TIM_OC_InitTypeDef sConfigOC = {0};

  htim3.Instance = TIM3;
  htim3.Init.Prescaler = 99;
  htim3.Init.CounterMode = TIM_COUNTERMODE_UP;
  htim3.Init.Period = 4999;
  htim3.Init.ClockDivision = TIM_CLOCKDIVISION_DIV1;
  htim3.Init.AutoReloadPreload = TIM_AUTORELOAD_PRELOAD_ENABLE;
  HAL_TIM_Base_Init(&htim3);

  sClockSourceConfig.ClockSource = TIM_CLOCKSOURCE_INTERNAL;
  HAL_TIM_ConfigClockSource(&htim3, &sClockSourceConfig);

  HAL_TIM_PWM_Init(&htim3);

  sMasterConfig.MasterOutputTrigger = TIM_TRGO_RESET;
  sMasterConfig.MasterSlaveMode = TIM_MASTERSLAVEMODE_DISABLE;
  HAL_TIMEx_MasterConfigSynchronization(&htim3, &sMasterConfig);

  sConfigOC.OCMode = TIM_OCMODE_PWM1;
  sConfigOC.Pulse = 0;
  sConfigOC.OCPolarity = TIM_OCPOLARITY_HIGH;
  sConfigOC.OCFastMode = TIM_OCFAST_DISABLE;
  HAL_TIM_PWM_ConfigChannel(&htim3, &sConfigOC, TIM_CHANNEL_2);

  HAL_TIM_MspPostInit(&htim3);
}

static void MX_TIM4_Init(void)
{
  TIM_ClockConfigTypeDef sClockSourceConfig = {0};
  TIM_MasterConfigTypeDef sMasterConfig = {0};

  htim4.Instance = TIM4;
  htim4.Init.Prescaler = 9;
  htim4.Init.CounterMode = TIM_COUNTERMODE_UP;
  htim4.Init.Period = 16799;
  htim4.Init.ClockDivision = TIM_CLOCKDIVISION_DIV1;
  htim4.Init.AutoReloadPreload = TIM_AUTORELOAD_PRELOAD_ENABLE;
  HAL_TIM_Base_Init(&htim4);

  sClockSourceConfig.ClockSource = TIM_CLOCKSOURCE_INTERNAL;
  HAL_TIM_ConfigClockSource(&htim4, &sClockSourceConfig);

  sMasterConfig.MasterOutputTrigger = TIM_TRGO_UPDATE;
  sMasterConfig.MasterSlaveMode = TIM_MASTERSLAVEMODE_DISABLE;
  HAL_TIMEx_MasterConfigSynchronization(&htim4, &sMasterConfig);

  NVIC_SetPriority(TIM4_IRQn, NVIC_EncodePriority(NVIC_GetPriorityGrouping(),0, 0));
  NVIC_EnableIRQ(TIM4_IRQn);
}

static void MX_TIM6_Init(void)
{
  TIM_MasterConfigTypeDef sMasterConfig = {0};

  htim6.Instance = TIM6;
  htim6.Init.Prescaler = 99;
  htim6.Init.CounterMode = TIM_COUNTERMODE_UP;
  htim6.Init.Period = 999;
  htim6.Init.AutoReloadPreload = TIM_AUTORELOAD_PRELOAD_ENABLE;
  HAL_TIM_Base_Init(&htim6);

  sMasterConfig.MasterOutputTrigger = TIM_TRGO_RESET;
  sMasterConfig.MasterSlaveMode = TIM_MASTERSLAVEMODE_DISABLE;
  HAL_TIMEx_MasterConfigSynchronization(&htim6, &sMasterConfig);
}

static void MX_TIM8_Init(void)
{
  TIM_ClockConfigTypeDef sClockSourceConfig = {0};
  TIM_MasterConfigTypeDef sMasterConfig = {0};

  htim8.Instance = TIM8;
  htim8.Init.Prescaler = 99;
  htim8.Init.CounterMode = TIM_COUNTERMODE_UP;
  htim8.Init.Period = 999;
  htim8.Init.ClockDivision = TIM_CLOCKDIVISION_DIV1;
  htim8.Init.RepetitionCounter = 0;
  htim8.Init.AutoReloadPreload = TIM_AUTORELOAD_PRELOAD_ENABLE;
  HAL_TIM_Base_Init(&htim8);

  sClockSourceConfig.ClockSource = TIM_CLOCKSOURCE_INTERNAL;
  HAL_TIM_ConfigClockSource(&htim8, &sClockSourceConfig);

  sMasterConfig.MasterOutputTrigger = TIM_TRGO_UPDATE;
  sMasterConfig.MasterOutputTrigger2 = TIM_TRGO2_RESET;
  sMasterConfig.MasterSlaveMode = TIM_MASTERSLAVEMODE_DISABLE;
  HAL_TIMEx_MasterConfigSynchronization(&htim8, &sMasterConfig);
}
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

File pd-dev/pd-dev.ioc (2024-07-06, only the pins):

Mcu.UserName=STM32G431K8Tx
PA0.Signal=ADC1_IN1
PA13.Signal=SYS_JTMS-SWDIO
PA14.Signal=SYS_JTCK-SWCLK
PA2.Signal=LPUART1_TX
PA3.Signal=LPUART1_RX
PB4.Signal=UCPD1_CC2
PB6.Signal=UCPD1_CC1

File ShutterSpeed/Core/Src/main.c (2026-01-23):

#include "main.h"
#include "usbpd.h"
#include "usb_device.h"
#include "usbd_cdc_if.h"

ADC_HandleTypeDef hadc1;
DMA_HandleTypeDef hdma_adc1;

COMP_HandleTypeDef hcomp2;

CORDIC_HandleTypeDef hcordic;

DAC_HandleTypeDef hdac1;

FMAC_HandleTypeDef hfmac;

RNG_HandleTypeDef hrng;

TIM_HandleTypeDef htim2;
TIM_HandleTypeDef htim4;
TIM_HandleTypeDef htim6;

void SystemClock_Config(void);
static void MX_GPIO_Init(void);
static void MX_DMA_Init(void);
static void MX_UCPD1_Init(void);
static void MX_ADC1_Init(void);
static void MX_CORDIC_Init(void);
static void MX_FMAC_Init(void);
static void MX_RNG_Init(void);
static void MX_TIM2_Init(void);
static void MX_TIM4_Init(void);
static void MX_TIM6_Init(void);
static void MX_COMP2_Init(void);
static void MX_DAC1_Init(void);

uint16_t adc[4]; // ADC buf
uint16_t aadc = 0;
uint16_t mod = 500;
enum fsm_states {IDLE = 0, PRE, WAIT, TRIGD, FIN, ERR};
struct fsm_t {
  uint8_t mode; // FSM mode
} fsm;
struct shut_t s = {.trigger = 0};

int main(void)
{
  HAL_Init();
  SystemClock_Config();

  MX_GPIO_Init();
  MX_DMA_Init();
  MX_UCPD1_Init();
  MX_USB_Device_Init();
  MX_ADC1_Init();
  MX_CORDIC_Init();
  MX_FMAC_Init();
  MX_RNG_Init();
  MX_TIM2_Init();
  MX_TIM4_Init();
  MX_TIM6_Init();
  MX_COMP2_Init();
  MX_DAC1_Init();

  // LED-TIM
  HAL_TIM_Base_Start_IT(&htim6);
  // ADC
  HAL_ADC_Start_DMA(&hadc1, (uint32_t *) &adc[0], 4);
  HAL_TIM_Base_Start_IT(&htim4);
  // DAC
  HAL_COMP_Start(&hcomp2);
  HAL_DAC_Start(&hdac1, DAC_CHANNEL_2);

  MX_USBPD_Init();
  while (1)
  {
    switch (fsm.mode){
      case PRE:
      default:

        HAL_Delay(500);
        aadc = ((adc[0] + adc[1] + adc[2] + adc[3]) / 4) - mod;
        HAL_DAC_SetValue(&hdac1, DAC_CHANNEL_2, DAC_ALIGN_12B_R, aadc);
        s.trigger = 0;

        if(0){
          fsm.mode = ERR;
        } else {
          fsm.mode = WAIT;
        }
        break;
      case WAIT:

        aadc = ((adc[0] + adc[1] + adc[2] + adc[3]) / 4) - mod;
        HAL_DAC_SetValue(&hdac1, DAC_CHANNEL_2, DAC_ALIGN_12B_R, aadc);
        s.trigger = 0;

        if(0){
          fsm.mode = ERROR;
        } else {
          fsm.mode = TRIGD;
        }
        break;
      case TRIGD:

        if(0){
          fsm.mode = ERROR;
        } else if(s.trigger == 2){
          fsm.mode = FIN;
        }
        break;
      case FIN:

        char tg[64];
        memset(tg, '\0' , 64);
        s.elapsed_time = (uint32_t)((float)(s.elapsed+1)*(float)(1.0/168.0));
        if(s.elapsed){
          s.speed = (1000000.0/(float)(s.elapsed_time));
        } else {
          s.speed = 0;
        }
        sprintf(tg, "%lulsb,\t%luus,\t1/%lus\r\n", s.elapsed,
                                          s.elapsed_time,
                                          s.speed);
        CDC_Transmit_FS((uint8_t *) tg, 64);

        s.trigger = 0;

        if (s.trigger == 0){
          fsm.mode = PRE;
        }
        break;
      case ERR:

        if(0){
          fsm.mode = PRE;
        }
        break;
    }
  }
}

void SystemClock_Config(void)
{
  RCC_OscInitTypeDef RCC_OscInitStruct = {0};
  RCC_ClkInitTypeDef RCC_ClkInitStruct = {0};

  HAL_PWREx_ControlVoltageScaling(PWR_REGULATOR_VOLTAGE_SCALE1_BOOST);

  RCC_OscInitStruct.OscillatorType = RCC_OSCILLATORTYPE_HSI|RCC_OSCILLATORTYPE_HSI48;
  RCC_OscInitStruct.HSIState = RCC_HSI_ON;
  RCC_OscInitStruct.HSICalibrationValue = RCC_HSICALIBRATION_DEFAULT;
  RCC_OscInitStruct.HSI48State = RCC_HSI48_ON;
  RCC_OscInitStruct.PLL.PLLState = RCC_PLL_ON;
  RCC_OscInitStruct.PLL.PLLSource = RCC_PLLSOURCE_HSI;
  RCC_OscInitStruct.PLL.PLLM = RCC_PLLM_DIV1;
  RCC_OscInitStruct.PLL.PLLN = 21;
  RCC_OscInitStruct.PLL.PLLP = RCC_PLLP_DIV2;
  RCC_OscInitStruct.PLL.PLLQ = RCC_PLLQ_DIV4;
  RCC_OscInitStruct.PLL.PLLR = RCC_PLLR_DIV2;
  if (HAL_RCC_OscConfig(&RCC_OscInitStruct) != HAL_OK)
  {
    Error_Handler();
  }

  RCC_ClkInitStruct.ClockType = RCC_CLOCKTYPE_HCLK|RCC_CLOCKTYPE_SYSCLK
                              |RCC_CLOCKTYPE_PCLK1|RCC_CLOCKTYPE_PCLK2;
  RCC_ClkInitStruct.SYSCLKSource = RCC_SYSCLKSOURCE_PLLCLK;
  RCC_ClkInitStruct.AHBCLKDivider = RCC_SYSCLK_DIV1;
  RCC_ClkInitStruct.APB1CLKDivider = RCC_HCLK_DIV1;
  RCC_ClkInitStruct.APB2CLKDivider = RCC_HCLK_DIV1;

  if (HAL_RCC_ClockConfig(&RCC_ClkInitStruct, FLASH_LATENCY_4) != HAL_OK)
  {
    Error_Handler();
  }
}

static void MX_ADC1_Init(void)
{
  ADC_MultiModeTypeDef multimode = {0};
  ADC_ChannelConfTypeDef sConfig = {0};

  hadc1.Instance = ADC1;
  hadc1.Init.ClockPrescaler = ADC_CLOCK_SYNC_PCLK_DIV4;
  hadc1.Init.Resolution = ADC_RESOLUTION_12B;
  hadc1.Init.DataAlign = ADC_DATAALIGN_RIGHT;
  hadc1.Init.GainCompensation = 0;
  hadc1.Init.ScanConvMode = ADC_SCAN_DISABLE;
  hadc1.Init.EOCSelection = ADC_EOC_SEQ_CONV;
  hadc1.Init.LowPowerAutoWait = DISABLE;
  hadc1.Init.ContinuousConvMode = DISABLE;
  hadc1.Init.NbrOfConversion = 1;
  hadc1.Init.DiscontinuousConvMode = DISABLE;
  hadc1.Init.ExternalTrigConv = ADC_EXTERNALTRIG_T4_TRGO;
  hadc1.Init.ExternalTrigConvEdge = ADC_EXTERNALTRIGCONVEDGE_RISING;
  hadc1.Init.DMAContinuousRequests = ENABLE;
  hadc1.Init.Overrun = ADC_OVR_DATA_PRESERVED;
  hadc1.Init.OversamplingMode = DISABLE;
  if (HAL_ADC_Init(&hadc1) != HAL_OK)
  {
    Error_Handler();
  }

  multimode.Mode = ADC_MODE_INDEPENDENT;
  if (HAL_ADCEx_MultiModeConfigChannel(&hadc1, &multimode) != HAL_OK)
  {
    Error_Handler();
  }

  sConfig.Channel = ADC_CHANNEL_3;
  sConfig.Rank = ADC_REGULAR_RANK_1;
  sConfig.SamplingTime = ADC_SAMPLETIME_2CYCLES_5;
  sConfig.SingleDiff = ADC_SINGLE_ENDED;
  sConfig.OffsetNumber = ADC_OFFSET_NONE;
  sConfig.Offset = 0;
  if (HAL_ADC_ConfigChannel(&hadc1, &sConfig) != HAL_OK)
  {
    Error_Handler();
  }
}

static void MX_COMP2_Init(void)
{
  hcomp2.Instance = COMP2;
  hcomp2.Init.InputPlus = COMP_INPUT_PLUS_IO2;
  hcomp2.Init.InputMinus = COMP_INPUT_MINUS_DAC1_CH2;
  hcomp2.Init.OutputPol = COMP_OUTPUTPOL_NONINVERTED;
  hcomp2.Init.Hysteresis = COMP_HYSTERESIS_70MV;
  hcomp2.Init.BlankingSrce = COMP_BLANKINGSRC_NONE;
  hcomp2.Init.TriggerMode = COMP_TRIGGERMODE_IT_RISING_FALLING;
  if (HAL_COMP_Init(&hcomp2) != HAL_OK)
  {
    Error_Handler();
  }
}

static void MX_CORDIC_Init(void)
{
  hcordic.Instance = CORDIC;
  if (HAL_CORDIC_Init(&hcordic) != HAL_OK)
  {
    Error_Handler();
  }
}
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

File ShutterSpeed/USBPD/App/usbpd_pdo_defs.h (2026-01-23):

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

#ifndef __USBPD_PDO_DEF_H_
#define __USBPD_PDO_DEF_H_

#ifdef __cplusplus
 extern "C" {
#endif

/* Includes ------------------------------------------------------------------*/
#include "usbpd_def.h"

/* Define   ------------------------------------------------------------------*/
#define PORT0_NB_SOURCEPDO         0U   /* Number of Source PDOs (applicable for port 0)   */
#define PORT0_NB_SINKPDO           1U   /* Number of Sink PDOs (applicable for port 0)     */
#define PORT1_NB_SOURCEPDO         0U   /* Number of Source PDOs (applicable for port 1)   */
#define PORT1_NB_SINKPDO           0U   /* Number of Sink PDOs (applicable for port 1)     */

/* Exported typedef ----------------------------------------------------------*/

/* USER CODE BEGIN typedef */
/**
  * @brief  USBPD Port PDO Structure definition
  *
  */
/* USER CODE END typedef */

/* Exported define -----------------------------------------------------------*/

/* USER CODE BEGIN Exported_Define */

#define USBPD_CORE_PDO_SRC_FIXED_MAX_CURRENT 3
#define USBPD_CORE_PDO_SNK_FIXED_MAX_CURRENT 1500

/* USER CODE END Exported_Define */

/* Exported constants --------------------------------------------------------*/

/* Exported macro ------------------------------------------------------------*/

/* Exported variables --------------------------------------------------------*/

#ifndef __USBPD_PWR_IF_C
extern uint32_t PORT0_PDO_ListSRC[USBPD_MAX_NB_PDO];
extern uint32_t PORT0_PDO_ListSNK[USBPD_MAX_NB_PDO];
#else
/* Definition of Source PDO for Port 0 */
uint32_t PORT0_PDO_ListSRC[USBPD_MAX_NB_PDO] =
{
  /* PDO 1 */ (0x00000000U),

  /* PDO 2 */ (0x00000000U),

  /* PDO 3 */ (0x00000000U),

  /* PDO 4 */ (0x00000000U),

  /* PDO 5 */ (0x00000000U),

  /* PDO 6 */ (0x00000000U),

  /* PDO 7 */ (0x00000000U),

};

/* Definition of Sink PDO for Port 0 */
uint32_t PORT0_PDO_ListSNK[USBPD_MAX_NB_PDO] =
{

  /* PDO 1 */
  (
    USBPD_PDO_TYPE_FIXED                 | /* Fixed supply PDO            */

    USBPD_PDO_SNK_FIXED_SET_VOLTAGE(5000U)         | /* Voltage in mV               */
    USBPD_PDO_SNK_FIXED_SET_OP_CURRENT(0U)     | /* Operating current in  mA            */

    /* Common definitions applicable to all PDOs, defined only in PDO 1 */
    USBPD_PDO_SNK_FIXED_FRS_NOT_SUPPORTED          | /* Fast Role Swap				 */
    USBPD_PDO_SNK_FIXED_DRD_SUPPORTED          | /* Dual-Role Data              */
    USBPD_PDO_SNK_FIXED_USBCOMM_NOT_SUPPORTED      | /* USB Communications          */
    USBPD_PDO_SNK_FIXED_EXT_POWER_NOT_AVAILABLE    | /* External Power              */
    USBPD_PDO_SNK_FIXED_HIGHERCAPAB_NOT_SUPPORTED   | /* Higher Capability           */
    USBPD_PDO_SNK_FIXED_DRP_NOT_SUPPORTED            /* Dual-Role Power             */
  ),

  /* PDO 2 */ (0x00000000U),

  /* PDO 3 */ (0x00000000U),

  /* PDO 4 */ (0x00000000U),

  /* PDO 5 */ (0x00000000U),

  /* PDO 6 */ (0x00000000U),

  /* PDO 7 */ (0x00000000U),
};

#endif

/* Exported functions --------------------------------------------------------*/

#ifdef __cplusplus
}
#endif

#endif /* __USBPD_PDO_DEF_H_ */

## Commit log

2023-05-10 added kicad files
    [analog-toolkit.kicad_pcb, analog-toolkit.kicad_sch]
2023-07-25 updated kicad files
    [analog-toolkit.kicad_pcb, analog-toolkit.kicad_sch]
2023-07-25 added drv5055 tesla probe code
2026-01-23 updated version
    [analog-toolkit.kicad_pcb, analog-toolkit.kicad_sch]
2026-01-23 added shutter speed sensor
2026-02-06 bumped improved version
    [analog-toolkit.kicad_pcb, analog-toolkit.kicad_sch]
2026-02-16 removed drc
    [analog-toolkit.kicad_pcb]
2026-02-16 updated BOM files for JLC
    [analog-toolkit-BOM.xls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]
2026-02-16 updated boards, replaced RGB led
    [analog-toolkit.kicad_pcb, analog-toolkit.kicad_sch]
2026-03-14 added r3
    [analog-toolkit.kicad_pcb, analog-toolkit.kicad_sch]
2026-03-14 added lid for r3
    [analog-toolkit-lid.kicad_pcb, analog-toolkit-lid.kicad_sch]

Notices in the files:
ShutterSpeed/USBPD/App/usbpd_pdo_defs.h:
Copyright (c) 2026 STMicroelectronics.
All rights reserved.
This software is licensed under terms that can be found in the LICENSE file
